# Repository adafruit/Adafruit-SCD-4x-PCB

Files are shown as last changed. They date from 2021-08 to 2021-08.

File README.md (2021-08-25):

## Adafruit SCD-4x CO2, Temperature and Humidity Sensor PCB

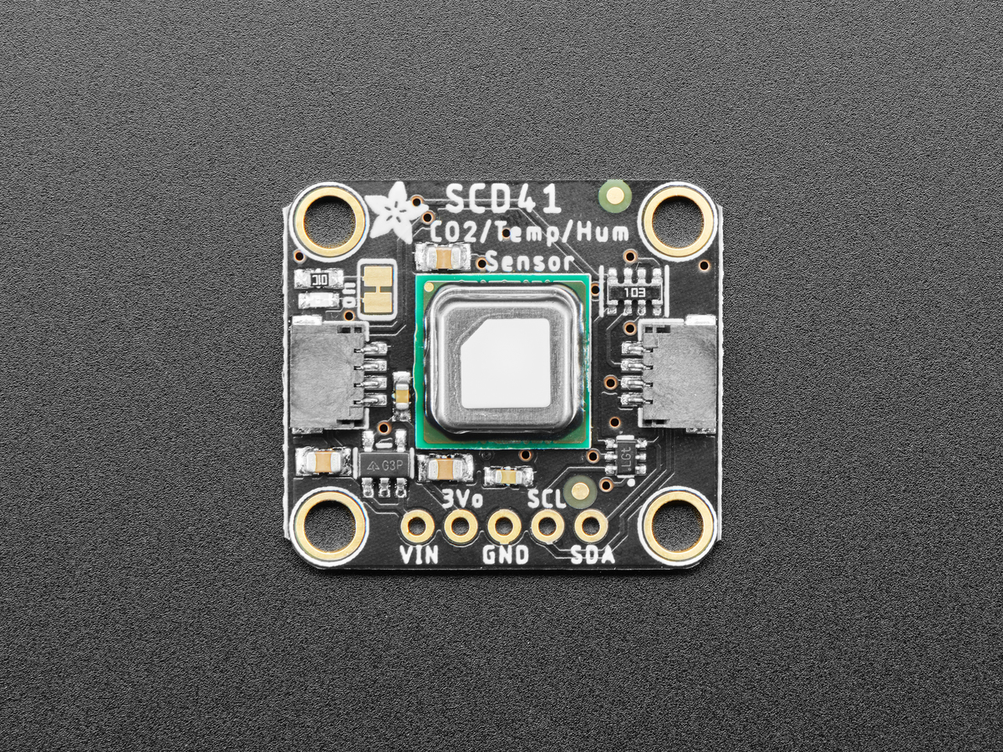
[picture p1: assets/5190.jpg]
<br/>
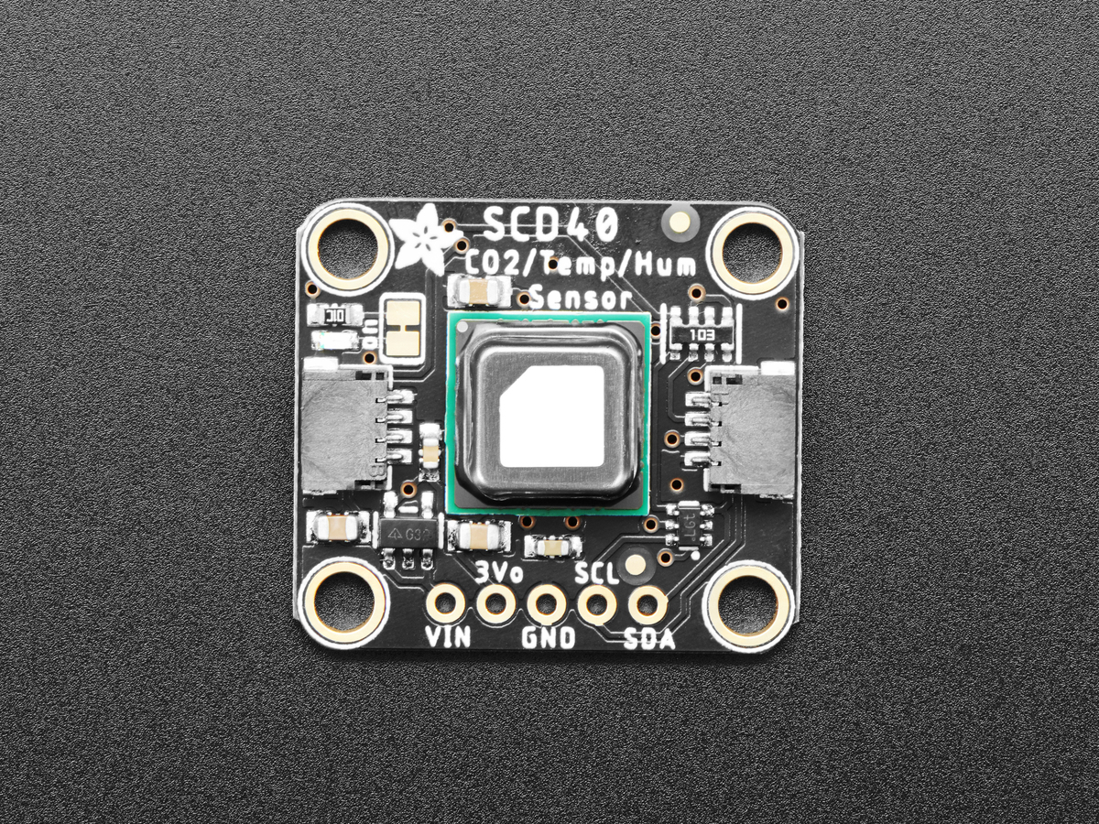
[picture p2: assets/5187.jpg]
<br/>
Click above to purchase one from the Adafruit shop!

PCB files for the Adafruit SCD-4x CO2, Temperature and Humidity Sensor. 

Format is EagleCAD schematic and board layout
* https://www.adafruit.com/product/5190

### Description

Take a deep breath in...now slowly breathe out. Mmm isn't it wonderful? All that air around us, which we bring into our lungs, extracts oxygen from and then breathes out carbon dioxide. CO2 is essential for life on this planet we call Earth - we and plants take turns using and emitting CO2 in an elegant symbiosis. But it's important to keep that CO2 balanced - you don't want too much around, not good for humans and not good for our planet.

The SCD-40 is a photoacoustic 'true' CO2 sensor that will tell you the CO2 PPM (parts-per-million) composition of ambient air. Unlike the SGP30, this sensor isn't approximating it from VOC gas concentration - it really is measuring the CO2 concentration! That means it's bigger and more expensive, but it is the real thing. Perfect for environmental sensing, scientific experiments, air quality and ventilation studies, and more.

Compared to the illustrious SCD-30, this sensor uses a different measurement technique, which allows it to be much smaller. The overall data quality should be very similar, however. Like the SCD-30, this sensor has data read over I2C, so it works very nicely with just about any microcontroller or microcomputer. There's both Arduino and Python/CircuitPython code so you can get started in a jiffy.

There are two variants of this sensor - the SCD-40 and SCD-41

* The SCD-40 is lower cost, and is perfect for indoor/outdoor air quality and CO2 measurements. It has a range of 400~2000 ppm with an accuracy of ±(50 ppm + 5% of reading)
* The SCD-41 is more expensive, and while it can definitely be used for air quality, it's wide range means its best used for industrial or scientific CO2 measurements where the ppm can get very high. It has a range of 400~5000 ppm with an accuracy of ±(40 ppm + 5% of reading)

Nice sensor, right? So we made it easy for you to get right into your next project. The sensor is soldered onto a custom-made PCB in the STEMMA QT form factor, making them easy to interface with. The STEMMA QT connectors on either side are compatible with the SparkFun Qwiic I2C connectors. This allows you to make solderless connections between your development board and the SCD-4x or to chain it with a wide range of other sensors and accessories using a compatible cable.

This sensor can run from 3.3 to 5V but it's more important for it to have a quiet power supply with low ripple, than any particular voltage. For that reason we've added a 3.3V regulator and level shifters: when connecting to a 5V microcontroller like an Arduino UNO the 5V supply is often shared with other electronic components that add noise. The onboard regulator will keep the voltage nice and quiet. For advanced hackers, they can cut/solder the back traces to change whether the regulator is enabled and what I2C logic level is desired.

### License

Adafruit invests time and resources providing this open source design, please support Adafruit and open-source hardware by purchasing products from [Adafruit](https://www.adafruit.com)!

Designed by Limor Fried/Ladyada for Adafruit Industries.

Creative Commons Attribution/Share-Alike, all text above must be included in any redistribution. 
See license.txt for additional details.

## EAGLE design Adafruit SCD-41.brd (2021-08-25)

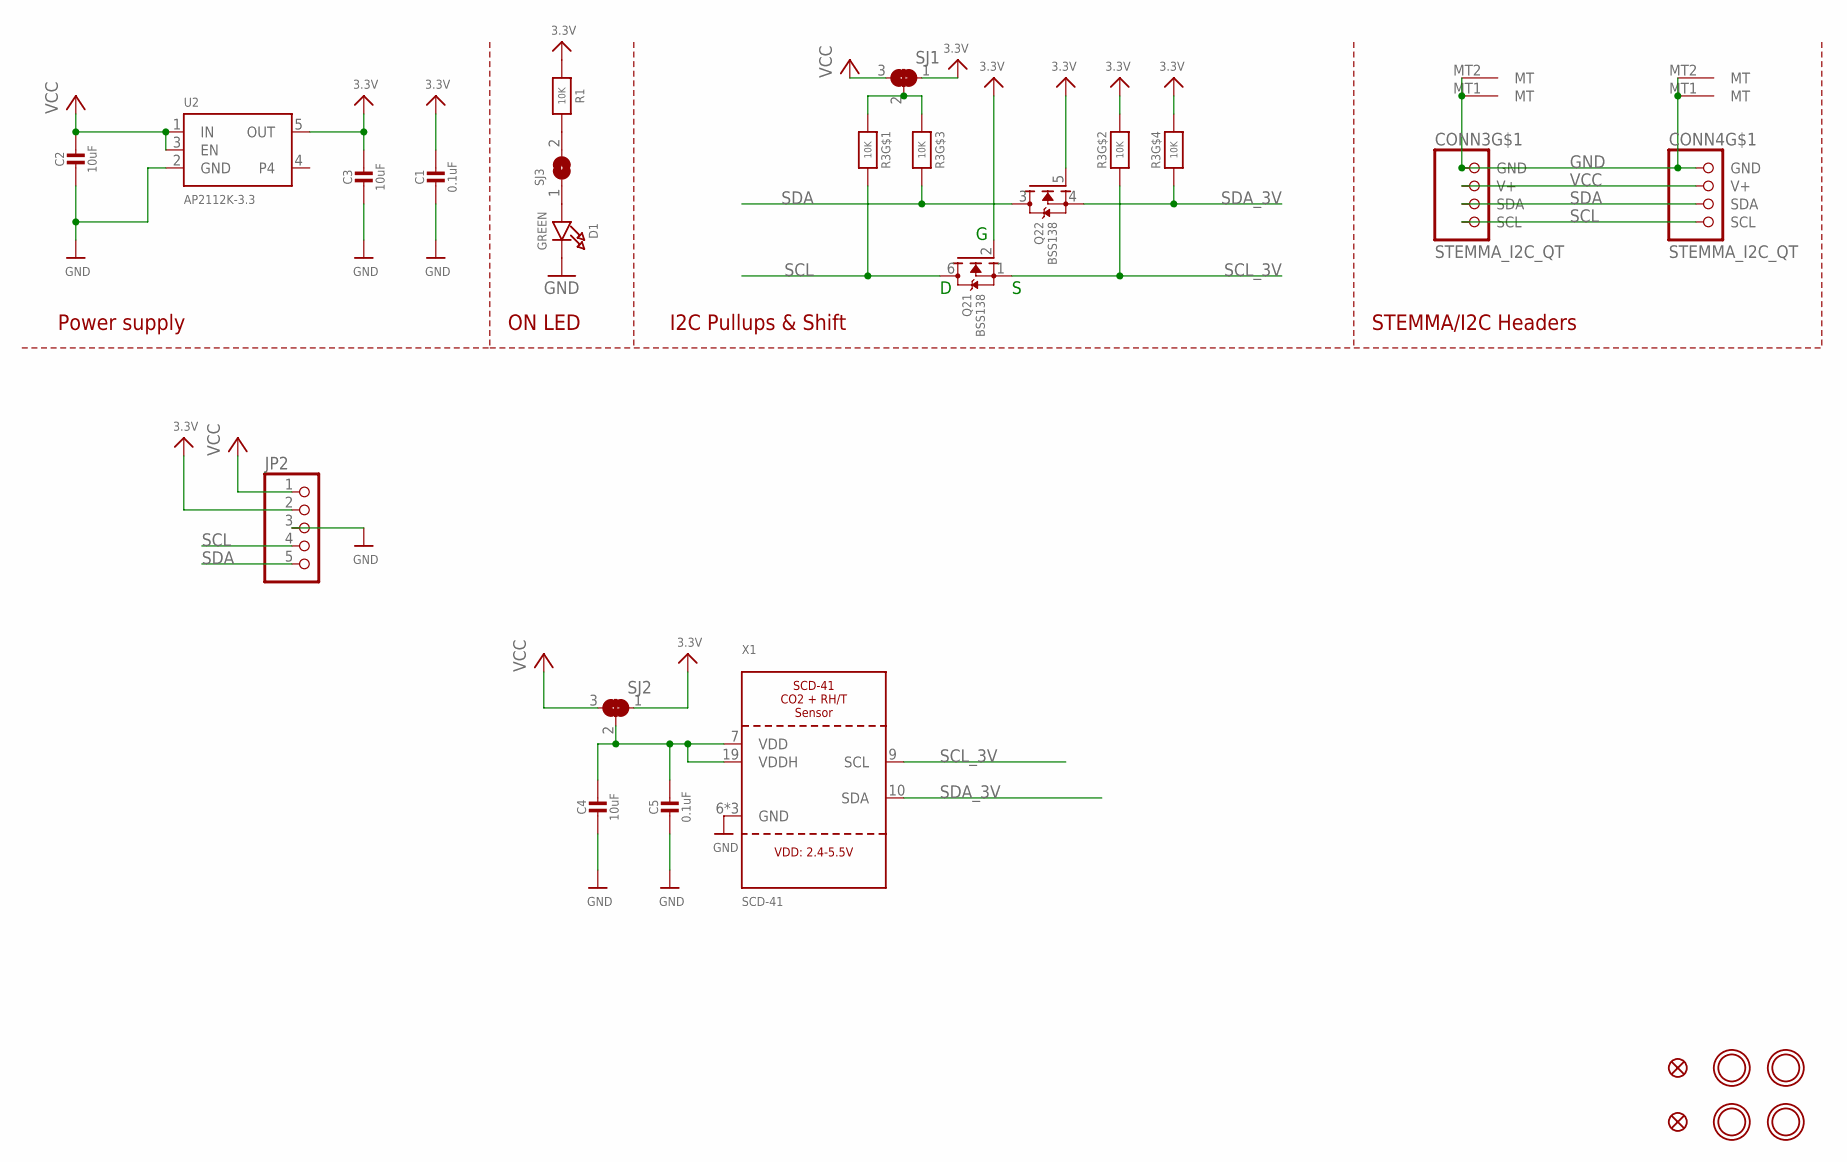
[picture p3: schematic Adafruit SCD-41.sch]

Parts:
C1, C5: 0.1uF; 0603-NO
C2, C3, C4: 10uF; 0805-NO
CONN3, CONN4: STEMMA_I2C_QT; JST_SH4
D1: GREEN; CHIPLED_0603_NOOUTLINE
FID3, FID4: FIDUCIAL_1MM
JP2: HEADER-1X576MIL; 1X05_ROUND_76
Q2: BSS138; SOT363
R1: 10K; 0603-NO
R3: 10K; RESPACK_4X0603
SJ1, SJ2: SOLDERJUMPER_2WAY; SOLDERJUMPER_2WAY_OPEN_NOPASTE
SJ3: SOLDERJUMPERCLOSED; SOLDERJUMPER_CLOSEDWIRE
U2: AP2112K-3.3; SOT23-5
U$1, U$17, U$19, U$21: MOUNTINGHOLE3.0THIN; MOUNTINGHOLE_3.0_PLATEDTHIN
X1: SCD-41; SCD41

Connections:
3.3V: C1.1, C3.1, JP2.2, Q2.2 (G), Q2.5 (G), R1.1, R3.2 (1), R3.4 (1), SJ1.1, SJ2.1, U2.5 (OUT)
GND: C1.2, C2.2, C3.2, C4.2, C5.2, CONN3.1 (GND), CONN3.MT1 (MT), CONN3.MT2 (MT), CONN4.1 (GND), CONN4.MT1 (MT), CONN4.MT2 (MT), D1.C, JP2.3, U2.2 (GND), X1.6 (GND), X1.20 (GND), X1.P$1 (GND)
unnamed: D1.A, SJ3.1
unnamed: R3.1, R3.3 (1), SJ1.2
unnamed: C4.1, C5.1, SJ2.2, X1.7 (VDD), X1.19 (VDDH)
unnamed: R1.2, SJ3.2
SCL: CONN3.4 (SCL), CONN4.4 (SCL), JP2.4, Q2.6 (D), R3.8 (2)
SCL_3V: Q2.1 (S), R3.7 (2), X1.9 (SCL)
SDA: CONN3.3 (SDA), CONN4.3 (SDA), JP2.5, Q2.3 (D), R3.6 (2)
SDA_3V: Q2.4 (S), R3.5 (2), X1.10 (SDA)
VCC: C2.1, CONN3.2 (V+), CONN4.2 (V+), JP2.1, SJ1.3, SJ2.3, U2.1 (IN), U2.3 (EN)

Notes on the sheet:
I2C Pullups & Shift
STEMMA/I2C Headers
ON LED
Power supply

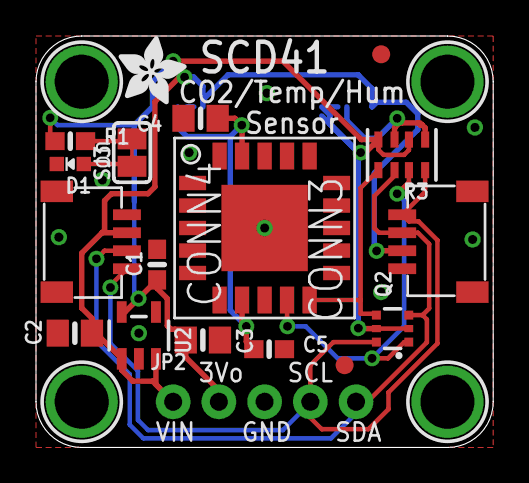
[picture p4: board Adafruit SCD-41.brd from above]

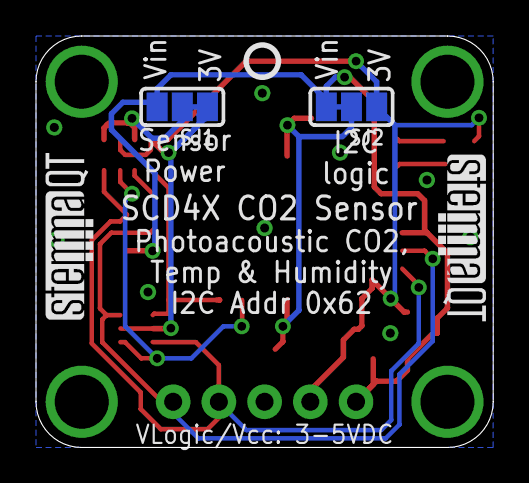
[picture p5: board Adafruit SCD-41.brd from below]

Board: 2 copper layers, 25.4 x 22.9 mm, 27 parts (5 on the bottom side), 11 nets.

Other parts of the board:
U$22: ADAFRUIT_3.5MM
U$25: PCBFEAT-REV-040
U$30, U$31: STEMMAQT

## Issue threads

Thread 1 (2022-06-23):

Mislabelled solder jumpers

omerk, 2022-06-23:
Hi,

There appears to be a mismatch between the silkscreen labels that annotate the solder jumpers and what they are actually connected to.

(I've added net names PU_PWR and SENSOR_VDD to highlight the issue)

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

So, SJ1 should really be "I2C logic" and SJ2 "Sensor Power". This is reversed in the board files in this repo and also the breakout I have in front of me.

ladyada, 2022-06-28:
woops - fixing on the next PCB run!
@kattni can u update the guide with an alert so people are bewarned :)

kattni, 2023-03-17:
Corrected silk has already been released in the shop. The guide has been updated to reflect the correct labels, and includes a warning about the initial run having incorrect labels. Thanks for reporting this!

Closed 2023-03-17.

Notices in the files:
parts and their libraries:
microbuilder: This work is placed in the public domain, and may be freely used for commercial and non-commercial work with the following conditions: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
